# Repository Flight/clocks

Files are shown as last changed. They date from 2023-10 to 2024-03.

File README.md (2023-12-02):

| Supported Targets | ESP32 | ESP32-C2 | ESP32-C3 | ESP32-C6 | ESP32-H2 | ESP32-P4 | ESP32-S2 | ESP32-S3 |
| --- | ----- | --- | --- | --- | --- | --- | --- | --- |

# ESP32 Clocks (ESP-IDF)

It connects to the Wi-Fi and syncs the time with the NTP server, showing the time and temperature on the screen. Optionally saving it to the external timer and showing the temperature from the sensor + from the API. Supports OTA Wi-Fi updates.

The project started from the dead section of the built-in clocks in my bath mirror and moved to my first experience with microcontrollers, C language and creating the home "lab".

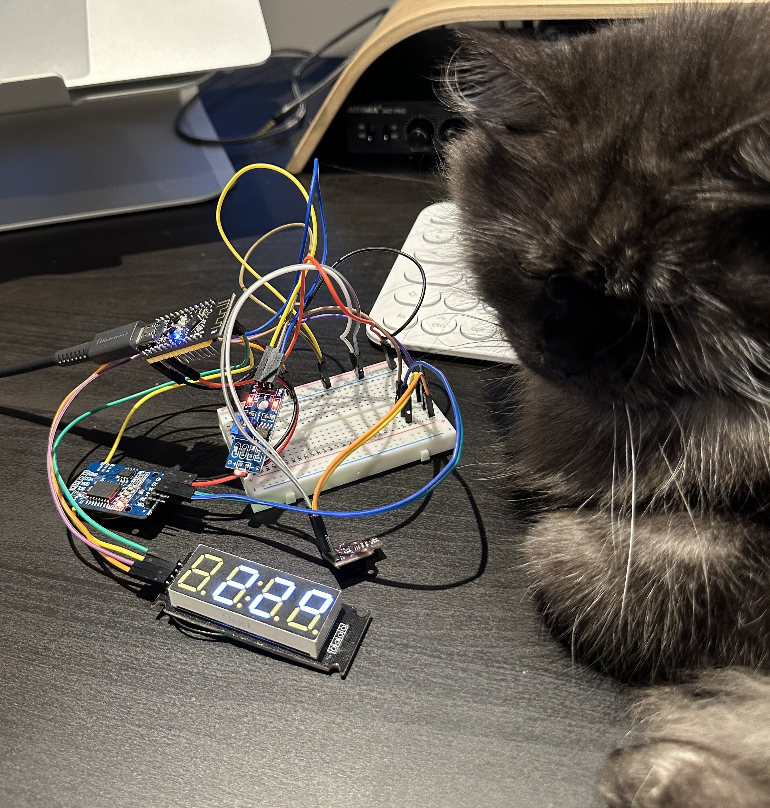
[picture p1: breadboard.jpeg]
Breadboard


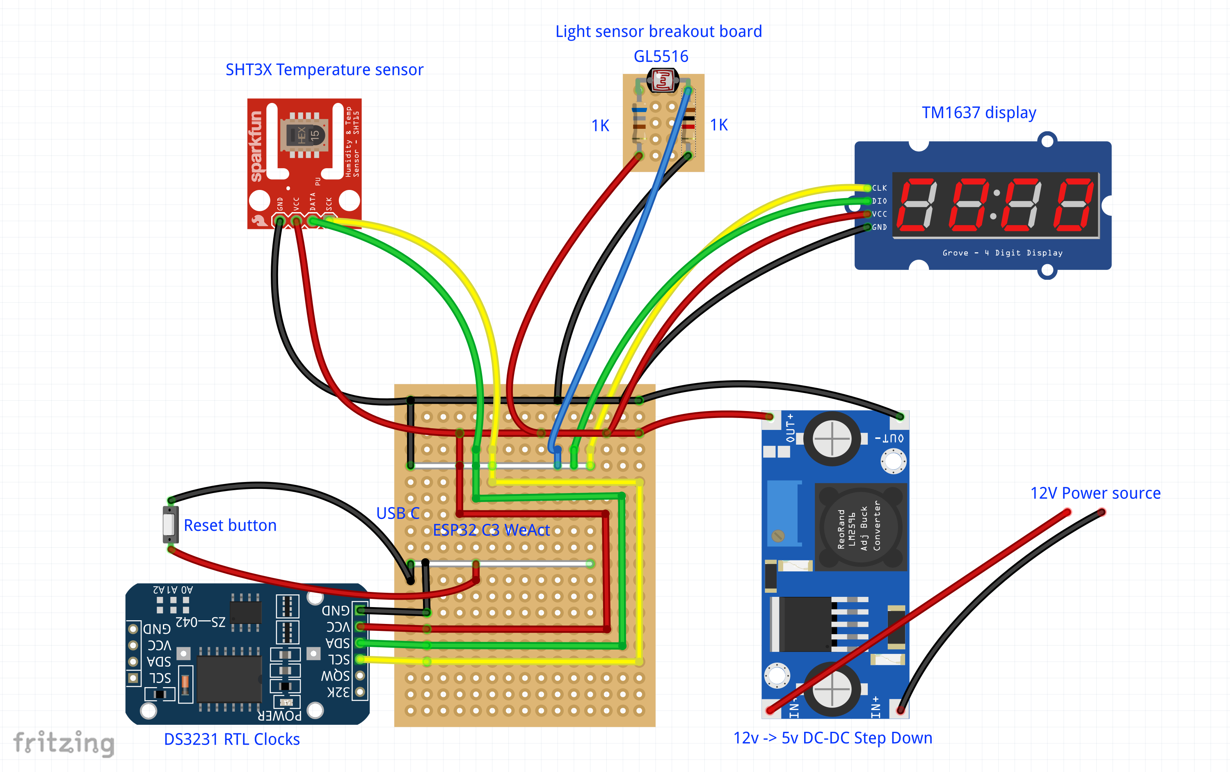
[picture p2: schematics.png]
Schematics

(green wires - data, yellow wires - clock, blue wire - low / high light sensor output)

## Features

- Based on **ESP32** microcontroller (tested with ESP32, ESP32C3 and ESP32S3). I've used the **[WeActStudio ESP32-C3FH4 Core Board](https://github.com/WeActStudio/WeActStudio.ESP32C3CoreBoard)**.

- **TM1637** 7-segment display.
- _Optional:_ **NTP Sync**
- _Optional:_ **DS3231** external timer. Saving time to the separate precise clocks.
- _Optional:_ **SHT3X** environment sensor. Measuring temperature (and optionally humidity).
- _Optional:_ **BMP280/BME280** environment sensor. Measuring temperature (and optionally humidity).
- _Optional:_ **DS1820** temperature sensor. Measuring temperature.
- _Optional:_ **Temperature from API** over Wi-Fi and HTTPS. [api.weatherapi.com](https://www.weatherapi.com)
- _Optional:_ **OTA Updates** over Wi-Fi and HTTPS.
- _Optional:_ **GL5516** Photo resistor. Switching between full and minimal brightness using ADC.
- _Optional:_ **HW-072** Light Sensor. Switching between full and minimal brightness based on the photoresistor output (both analog and digital).

## Requirements

The project was created using [ESP-IDF plugin](https://docs.espressif.com/projects/esp-idf/en/latest/esp32/get-started/) for Visual Studio Code and [ESP-IDF-LIB](https://esp-idf-lib.readthedocs.io/en/latest/).

## Initial setup

1. Clone the repo `git clone git@github.com:Flight/clocks.git` and go inside: `cd clocks`.
2. Generate the certificate for weatherapi.com

   `echo -n | openssl s_client -connect 192.168.50.100:443 | sed -ne '/-BEGIN CERTIFICATE-/,/-END CERTIFICATE-/p' > main/weather_from_api/api_weatherapi_com.pem`

3. Generate a certificate for the OTA Updates. Please **don't forget to fill the server name** on this step:

   **Common Name (e.g. server FQDN or YOUR name) []: 192.168.50.100** (your local IP address).

   `openssl req -newkey rsa:2048 -new -nodes -x509 -days 365 -keyout ota_server/key.pem -out main/ota_update/cert.pem`

4. Change the settings.
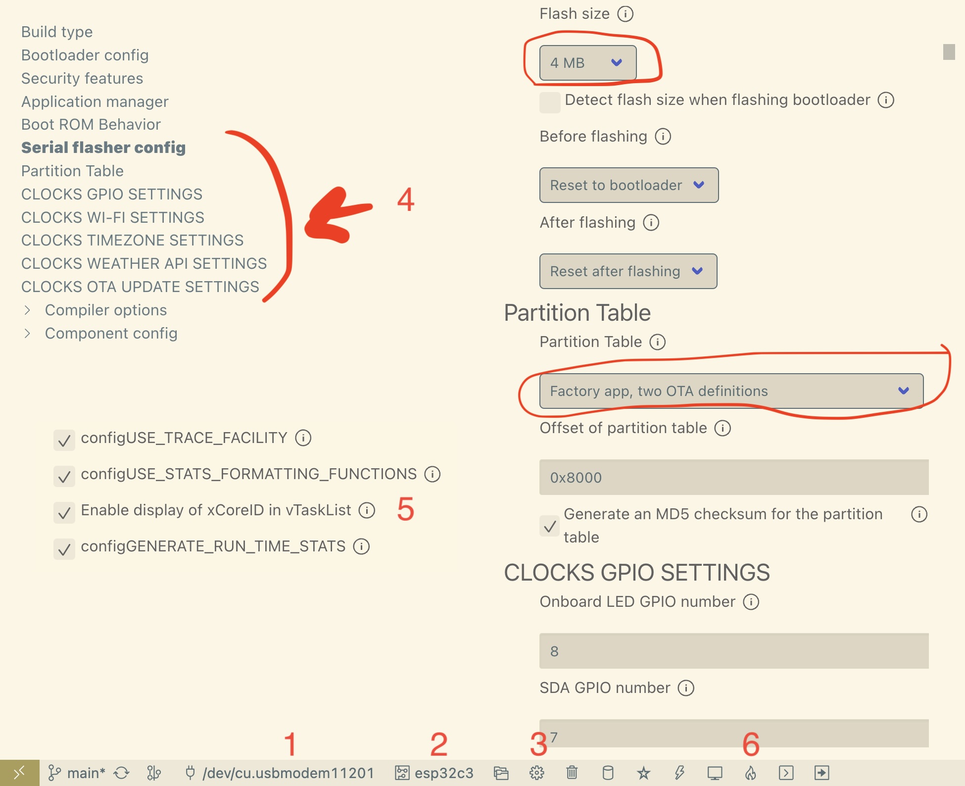
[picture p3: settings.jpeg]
Settings
   

## Run the project

Run the project using the **ESP-IDF Build, Flash and Monitor** button (number 6 on the screenshot).

## OTA Wi-Fi Updates

### Initial Checklist

- **Flash size** according to the settings on the screenshot (> 4 MB is needed for OTA).
- **Partition table** in settings
- **Firmware upgrade endpoint URL** in the Clocks OTA Update section.
- Generated the **certificate** `main/ota_update/cert.pem`.

### Run OTA Update

1. Create new GIT Tag

   `git tag -a v0.0.1 -m "new release"`

   `git push origin v0.0.1` (optional)

2. Run OTA web-server from `ota_server` folder. I'm using this [http-server](https://github.com/http-party/http-server) as **OpenSSL one didn't work properly** and was hanging during download until you don't stop it manually.

   `cd ota_server`

   `sudo npx http-server -S -C ../main/ota_update/cert.pem -p 8070 -c-1`

3. Drop the file `clocks.bin` to `ota_server` folder or setup the build to generate the output file in that folder.

   You can find the `main.bin` in the `build` folder after you built it. Just copy and rename it to `clocks.bin`.

4. Restart the ESP32. It will automatically start update process in 10 seconds after boot.

## Next steps

- ~~Replace the light sensor with the one which supports dead-zone to prevent blinking when the light is near the threshold.~~ (Done)
- ~~Compare OTA versions to prevent cycle update.~~ (Done)
- Replace the Legacy ADC lib with adc_oneshot.h as ESP-IDF suggests.
- Show if it would be rainy on the display.
- Web server with ESP_LOG outputs. The device already supports OTA Wi-Fi updates, so it will make it even easier.
- Check updates from FTP server or Samba directly from the router.
- Rewrite TM1637 lib as it isn't perfect.
- Add the human presense sensor like LD2410 and turn off the screen if there is nobody in the bath to prevent display degradation. Maybe can add some other cool features with it.

## More photos

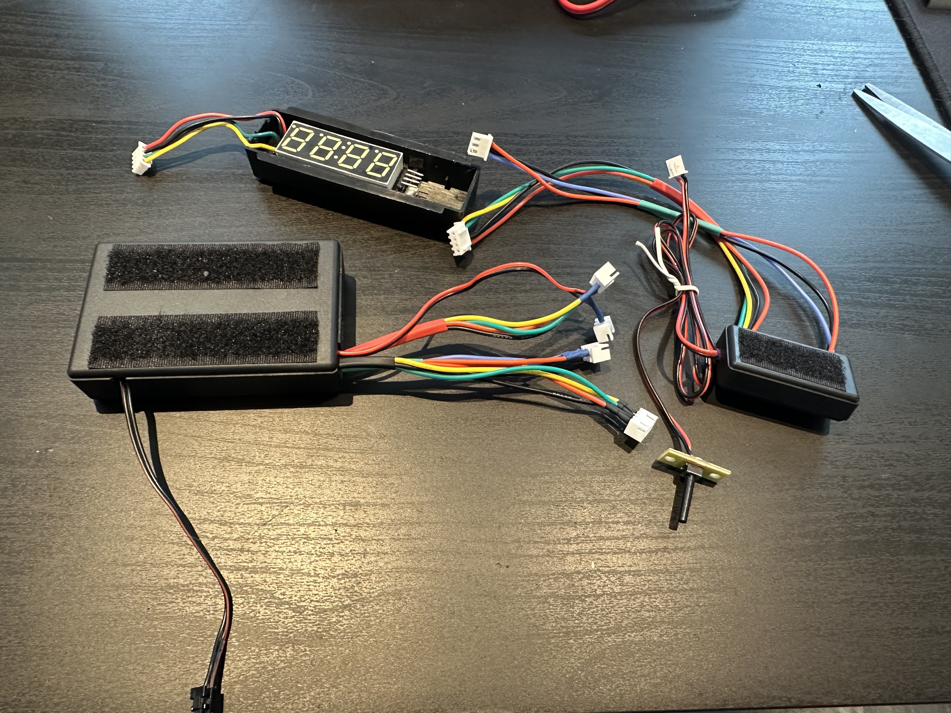
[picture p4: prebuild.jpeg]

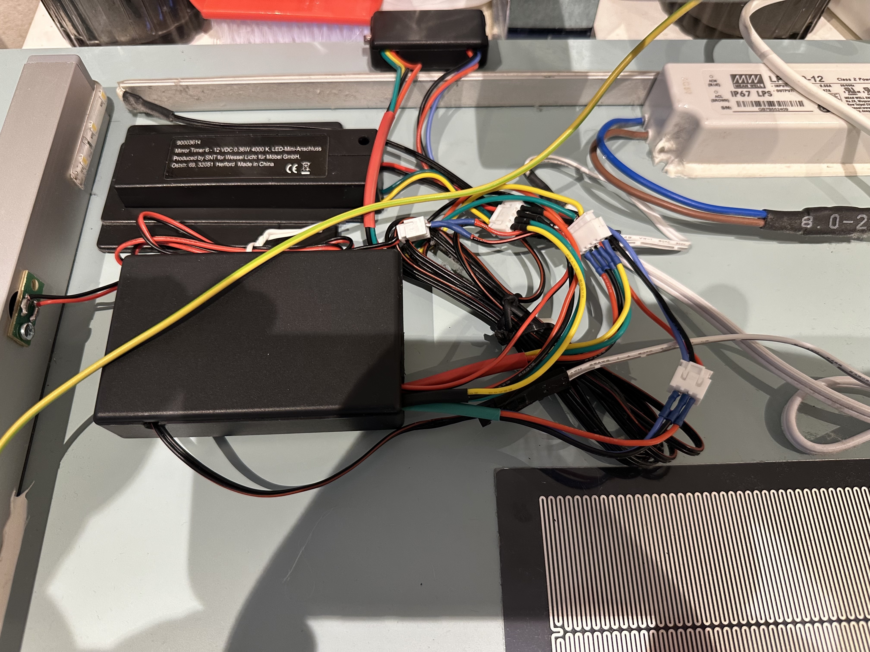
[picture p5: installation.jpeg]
Installation

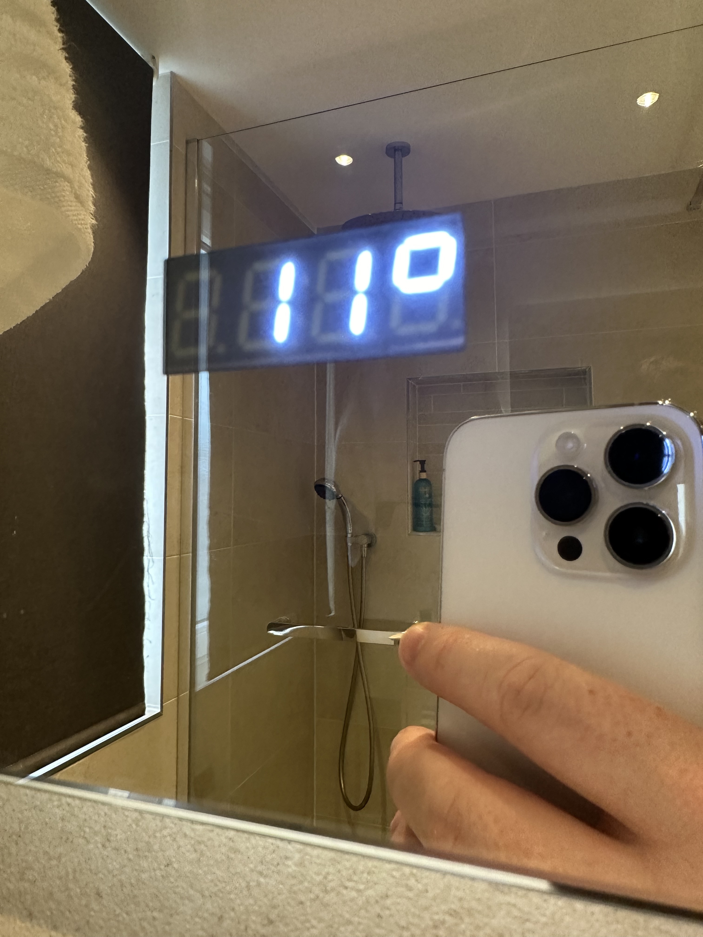
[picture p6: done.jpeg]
Done

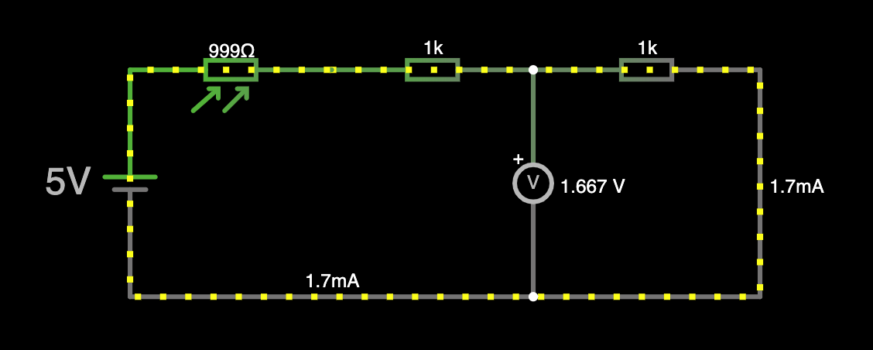
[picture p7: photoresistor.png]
Photoresistor


## Folder contents

The project **clocks** contains the entry point file in C language [main.c](main/main.c). The file is located in folder [main](main).

ESP-IDF projects are built using CMake. The project build configuration is contained in `CMakeLists.txt`
files that provide set of directives and instructions describing the project's source files and targets
(executable, library, or both).

Below is short explanation of remaining files in the project folder.

```
├── CMakeLists.txt
├── main
│   ├── CMakeLists.txt
│   └── main.c
└── README.md
```

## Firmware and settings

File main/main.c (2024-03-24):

#include <freertos/FreeRTOS.h>
#include <freertos/task.h>
#include <freertos/event_groups.h>
#include <stdio.h>
#include <nvs_flash.h>
#include <esp_system.h>
#include <time.h>
#include <esp_log.h>

#include "sdkconfig.h"
#include "i2cdev.h"

#include "global_event_group.h"

#include "spiffs_initialise/spiffs_initialise.h"
#include "custom_logs_handler/custom_logs_handler.h"
#include "system_state/system_state.h"
#include "led/led.h"
#include "wifi/wifi.h"
#include "webserver/webserver.h"
#include "light/light.h"
#include "display/display.h"
#include "time/external_timer.h"
#include "time/ntp.h"
#include "temperature_from_sensor/temperature_from_sensor.h"
#include "weather_from_api/weather_from_api.h"
#include "ota_update/ota_update.h"

EventGroupHandle_t global_event_group;
float global_inside_temperature = TEMPERATURE_ERROR_CODE;

static const char *TIMEZONE = CONFIG_TIMEZONE;

void app_main(void)
{
  spiffs_initialise();
  open_logs_file();
  esp_log_set_vprintf(&custom_logs_handler);

  esp_err_t err = nvs_flash_init();
  if (err == ESP_ERR_NVS_NO_FREE_PAGES || err == ESP_ERR_NVS_NEW_VERSION_FOUND)
  {
    nvs_flash_erase();
    nvs_flash_init();
  }

  global_event_group = xEventGroupCreate();
  i2cdev_init();

  setenv("TZ", TIMEZONE, 1);
  tzset();

  xTaskCreatePinnedToCore(&led_task, "LED", configMINIMAL_STACK_SIZE * 2, NULL, 1, NULL, 1);
  xTaskCreatePinnedToCore(&wifi_task, "Wi-Fi Keeper", configMINIMAL_STACK_SIZE * 3, NULL, 1, NULL, 1);
  xTaskCreatePinnedToCore(&light_sensor_task, "Light Sensor", configMINIMAL_STACK_SIZE * 2, NULL, 1, NULL, 1);
  xTaskCreatePinnedToCore(&webserver_task, "Webserver", configMINIMAL_STACK_SIZE * 4, NULL, 1, NULL, 1);
  xTaskCreatePinnedToCore(&external_timer_task, "External Timer", configMINIMAL_STACK_SIZE * 2, NULL, 1, NULL, 1);
  xTaskCreatePinnedToCore(&ntp_task, "NTP Sync", configMINIMAL_STACK_SIZE * 2, NULL, 1, NULL, 1);
  xTaskCreatePinnedToCore(&lcd_tm1637_task, "LCD TM1637", configMINIMAL_STACK_SIZE * 2, NULL, 1, NULL, 1);
  // xTaskCreatePinnedToCore(&temperature_from_SHT3X_sensor_task, "Temp SHT3X", configMINIMAL_STACK_SIZE * 2, NULL, 1, NULL, 1);
  // xTaskCreatePinnedToCore(&temperature_from_BMP280_sensor_task, "Temp BMP280", configMINIMAL_STACK_SIZE * 2, NULL, 1, NULL, 1);
  xTaskCreatePinnedToCore(&temperature_from_DS1820_sensor_task, "Temp DS1820", configMINIMAL_STACK_SIZE * 2, NULL, 1, NULL, 1);
  xTaskCreatePinnedToCore(&weather_from_api_task, "Weather API", configMINIMAL_STACK_SIZE * 3, NULL, 1, NULL, 1);
  xTaskCreatePinnedToCore(&ota_update_task, "OTA Update", configMINIMAL_STACK_SIZE * 4, NULL, 1, NULL, 1);
  xTaskCreatePinnedToCore(&system_state_task, "System State", configMINIMAL_STACK_SIZE * 2, NULL, 1, NULL, 1);
}

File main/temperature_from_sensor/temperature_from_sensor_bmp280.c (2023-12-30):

#include <freertos/FreeRTOS.h>
#include <freertos/task.h>
#include <driver/gpio.h>
#include <esp_log.h>
#include <string.h>

#include "sdkconfig.h"
#include "bmp280.h"
#include "global_event_group.h"

#include "temperature_from_sensor.h"

#define PORT 0
#define ADDR CONFIG_SHT3X_ADDR

static const char *TAG = "BMP280 Sensor";

static const gpio_num_t SDA_PIN = CONFIG_SDA_PIN;
static const gpio_num_t SCL_PIN = CONFIG_SCL_PIN;

static const uint8_t REFRESH_INTERVAL_MINS = 1;

void temperature_from_BMP280_sensor_task(void *pvParameter)
{
  float pressure;
  float temperature;
  float humidity;

  ESP_LOGI(TAG, "Init start");
  bmp280_params_t params;
  bmp280_init_default_params(&params);
  bmp280_t sensor;
  memset(&sensor, 0, sizeof(bmp280_t));
  bmp280_init_desc(&sensor, BMP280_I2C_ADDRESS_0, 0, SDA_PIN, SCL_PIN);
  esp_err_t err = bmp280_init(&sensor, &params);

  if (err != ESP_OK)
  {
    ESP_LOGW(TAG, "Sensor not found, cleaning the task");
    vTaskDelete(NULL);
  }

  bool bme280p = sensor.id == BME280_CHIP_ID;
  ESP_LOGI(TAG, "BMP280: found %s", bme280p ? "BME280" : "BMP280");
  ESP_LOGI(TAG, "Init end");

  while (true)
  {
    xEventGroupClearBits(global_event_group, IS_INSIDE_TEMPERATURE_READING_DONE_BIT);
    if (bmp280_read_float(&sensor, &temperature, &pressure, &humidity) == ESP_OK)
    {
      ESP_LOGI(TAG, "Pressure: %.2f Pa, Temperature: %.2f° C", pressure, temperature);
      if (bme280p)
      {
        ESP_LOGI(TAG, "Humidity: %.2f\n", humidity);
      }
      global_inside_temperature = temperature;
      xEventGroupSetBits(global_event_group, IS_INSIDE_TEMPERATURE_READING_DONE_BIT);
      vTaskDelay(1000 * 60 * REFRESH_INTERVAL_MINS / portTICK_PERIOD_MS);
      continue;
    }

    ESP_LOGE(TAG, "Can't measure the temperature");
    vTaskDelay(1000 * 60 * REFRESH_INTERVAL_MINS / portTICK_PERIOD_MS);
  }
}

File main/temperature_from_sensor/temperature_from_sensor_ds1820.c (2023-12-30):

#include <freertos/FreeRTOS.h>
#include <freertos/task.h>
#include <inttypes.h>
#include <driver/gpio.h>
#include <esp_log.h>
#include <string.h>
#include <ds18x20.h>
#include <inttypes.h>

#include "sdkconfig.h"
#include "global_event_group.h"

#include "temperature_from_sensor.h"

static const gpio_num_t SENSOR_GPIO = CONFIG_ONEWIRE_GPIO;
static const uint8_t REFRESH_INTERVAL_MINS = 1;

static const char *TAG = "DS1820 Temperature Sensor";

uint64_t find_sensor_address()
{
  size_t sensor_count = 0;
  onewire_addr_t addrs[1];

  ds18x20_scan_devices(SENSOR_GPIO, addrs, 1, &sensor_count);

  if (sensor_count > 0)
  {
    ESP_LOGI(TAG, "Sensor address: %lld", addrs[0]);
    return addrs[0];
  }
  else
  {
    ESP_LOGE(TAG, "No sensors found!");
    return 0;
  }
}

void temperature_from_DS1820_sensor_task(void *pvParameter)
{
  // Not needed if there is a pull-up resistor on the data line (4.7k)
  // gpio_set_pull_mode(SENSOR_GPIO, GPIO_PULLUP_ONLY);

  float temperature;
  uint64_t sensor_address = find_sensor_address();

  if (sensor_address == 0)
  {
    ESP_LOGW(TAG, "Sensor not found, cleaning the task");
    vTaskDelete(NULL);
  }

  while (true)
  {
    xEventGroupClearBits(global_event_group, IS_INSIDE_TEMPERATURE_READING_DONE_BIT);

    if (ds18x20_measure_and_read(SENSOR_GPIO, sensor_address, &temperature) == ESP_OK)
    {
      ESP_LOGI(TAG, "Temperature: %.2f° C", temperature);
      global_inside_temperature = temperature;
      xEventGroupSetBits(global_event_group, IS_INSIDE_TEMPERATURE_READING_DONE_BIT);
    }
    else
    {
      ESP_LOGE(TAG, "Can't measure the temperature");
    }

    vTaskDelay(1000 * 60 * REFRESH_INTERVAL_MINS / portTICK_PERIOD_MS);
  }
}

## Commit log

2023-10-06 TM1637 git submodule replaced with CMakeLists command, event groups
    [display.c, main.c, temperature.c]
2023-10-08 Light sensor added
2023-10-09 Inside temperature logic added
2023-10-20 Display shows time and sensor's temperature
2023-10-22 Outside temperature display done
2023-10-22 Board changed to ESP32-C3Fx4 (WeAct Studio)
2023-10-29 DS3231 sensor connected, brightness fix, NTP sync improved
    [display.c, external_timer.c, light.c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]
2023-10-29 System state added, memory optimised, initial brightness fix
    [external_timer.c, light.c, main.c]
2023-10-30 OTA update fix, temperature from API fix
    [main.c]
2023-11-04 Readme schematics added
2023-11-05 Readme updated, final setup photos, fritzing schematics
    [clocks.fzz]
2023-11-06 Chunked temperature API response handling added, don't show outdated temperature
2023-11-09 OTA updates binary version check implemented (no update loop anymore), temperature sensor offset added
2023-11-15 External timer temperature removed
2023-11-16 Auto restart, light sensor ADC with drifting, memory leaks fix, BME680 replaced with SHT3X
    [light.c, main.c]
2023-11-17 JSON parse memory leak fix
    [main.c]
2023-11-17 Analog photo diode support added, shecmatics, readme
2023-11-18 System uptime print added
2023-11-19 OTA task fixes, system state task fixes
    [main.c]
2023-11-19 New temp and light sensors enabled
2023-11-21 BMP280/BME280 Temperature sensor support added
2023-12-01 DS1820 temperature sensor support added, ADC oneshot mode added, photoresistor resistance changed
2023-12-02 Weather from API memory leak fix, 0 temperature fix
    [display.c, main.c]
2023-12-02 Preparation for OTA for v1 version of sensor
2023-12-03 Brightness levels added, basic webserver added, old sensors cleanup, inside temperature 0C fix
    [display.c, light.c, main.c]
2023-12-05 Temperature sensors detection
2023-12-20 Light sensors settings saving / getting from NVS
2023-12-21 External timer fix
2023-12-27 Logs to spiffs preparations
    [partitions.csv]
2023-12-30 Logs file output UTF8, cleaning logs file if too big
    [temperature_from_sensor_bmp280.c, temperature_from_sensor_ds1820.c, webserver.c]
2024-04-07 Daylight saving time fix
    [external_timer.c]
